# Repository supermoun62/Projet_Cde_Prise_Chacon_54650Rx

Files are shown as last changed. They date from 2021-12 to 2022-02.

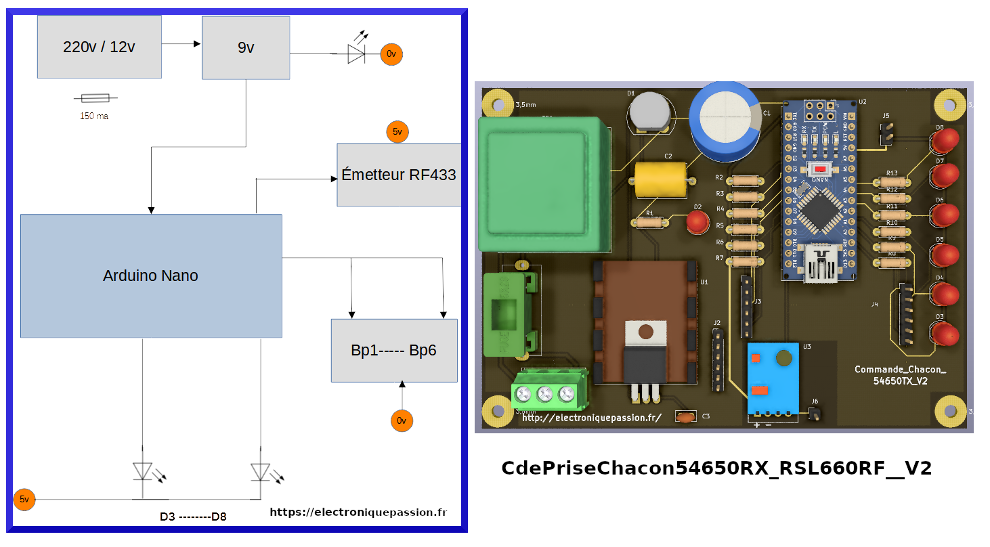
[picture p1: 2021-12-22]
Synopsis_CdePriseChacon54650RX_RSL660RF_Total.png

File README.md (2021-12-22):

# Projet_Cde_Prise_Chacon_54650Rx_ RSL3660R-F

Piloter 6 prises Chacon. L'ensemble comprend:

    Programmes Arduino:

    ReceiveDemo_Advanced
	ReceiveDemo_Simple
	CdePriseChacon54650RX_RSL660RF__V1
	CdePriseChacon54650RX_RSL660RF__V2

    Librairies rc_switch-2.6.3 et simpleBouton.

    Liste du matériel.

    Les schémas.
	Schema_Cde_Prise_Chacon_54650Rx_V1
	Schema_Cde_Prise_Chacon_54650Rx_V2
	Schema_Decodage_Chacon_54650TX

    Documentations Techniques.

    PCB en Gerber.

    PCB en PDF.

    Le fichier Arduino-Chacon_54650Rx_ RSL3660R-F.pdf
	contient le détail du projet.

   https://github.com/supermoun62/Projet_Cde_Prise_Chacon_54650Rx/blob/main/Synopsis_CdePriseChacon54650RX_RSL660RF_Total.png

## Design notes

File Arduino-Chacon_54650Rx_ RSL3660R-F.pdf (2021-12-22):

Arduino - Chacon_54650Rx_ RSL3660R-F

Arduino-Chacon_54650Rx_ RSL3660R-F | http://electroniquepassion.fr

### 1 Sur 19

## PROJET

Remplacer la télécommande Chacon Ref :54650RX_RSL3660R-F par un Arduino

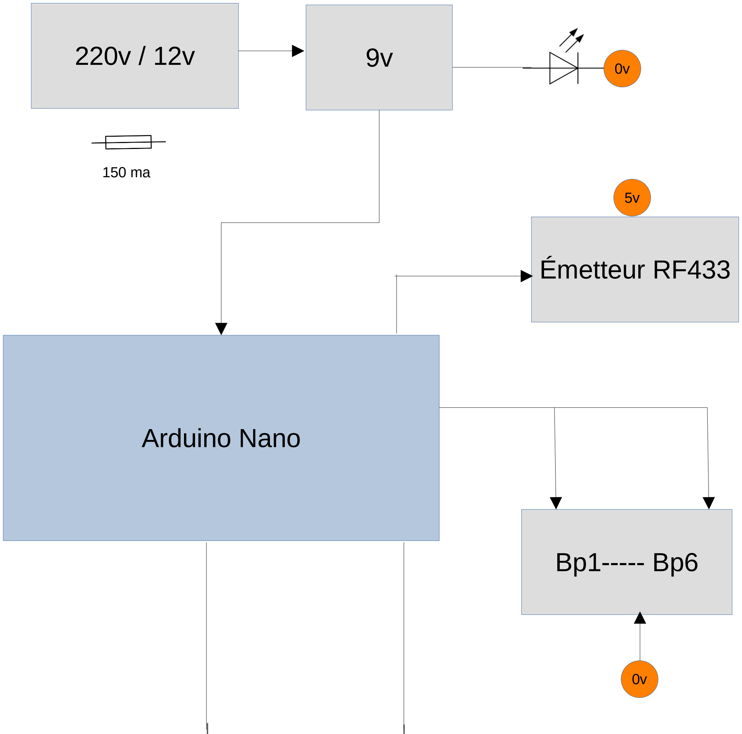
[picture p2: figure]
Arduino Nano; Émetteur RF433

### 2 Sur 19

Synopsis

5v
D3 --------D8

Matériel utilisé :

Télécommande Chacon : 54650TX_RSL366T

Prise Chacon : 54650RX-RSL3660R-F

Source : (https://github.com/sui77/rc-switch) | ReceiveDemo_Simple (https://github.com/sui77/rc-switch/tree/master/examples/ReceiveDemo_Simple) ReceiveDemo_Advanced (https://github.com/sui77/rc-switch/tree/master/examples/ReceiveDemo_Advanced)
Librairies : (https://github.com/sui77/rc-switch) | rc-switch (https://github.com/sui77/rc-switch)
| simpleBouton 1.4.2 (https://forum.arduino.cc/t/partage-boutons-poussoirs/361656)

### 3 Sur 19

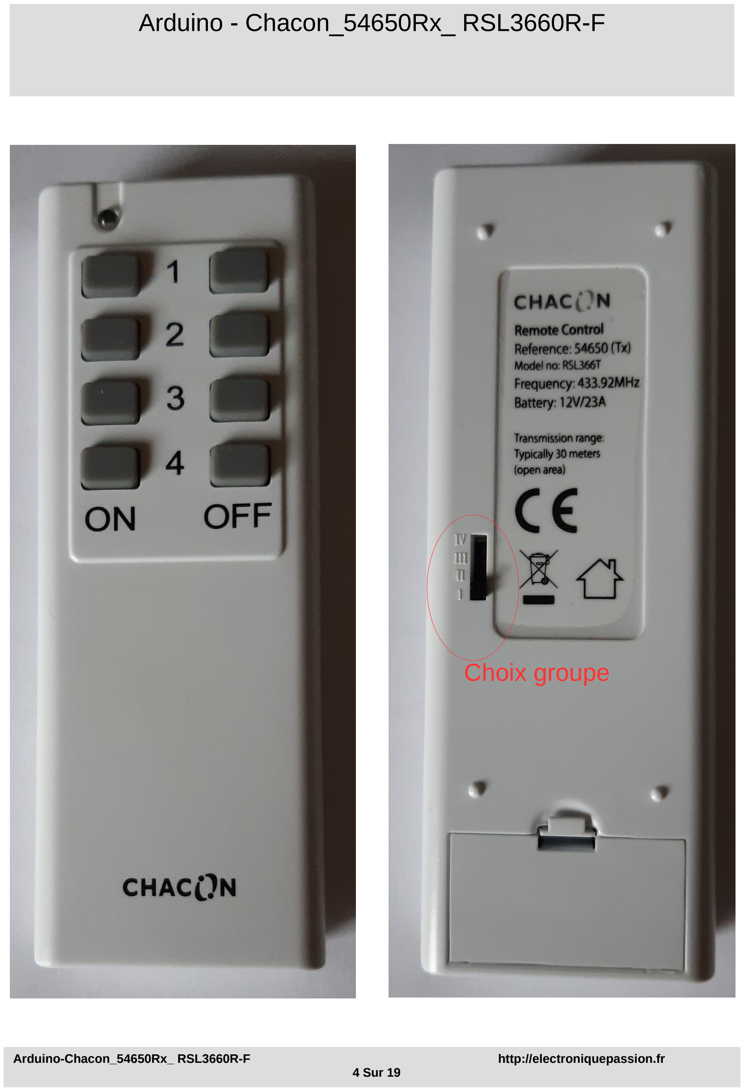
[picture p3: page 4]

Choix groupe

### 4 Sur 19

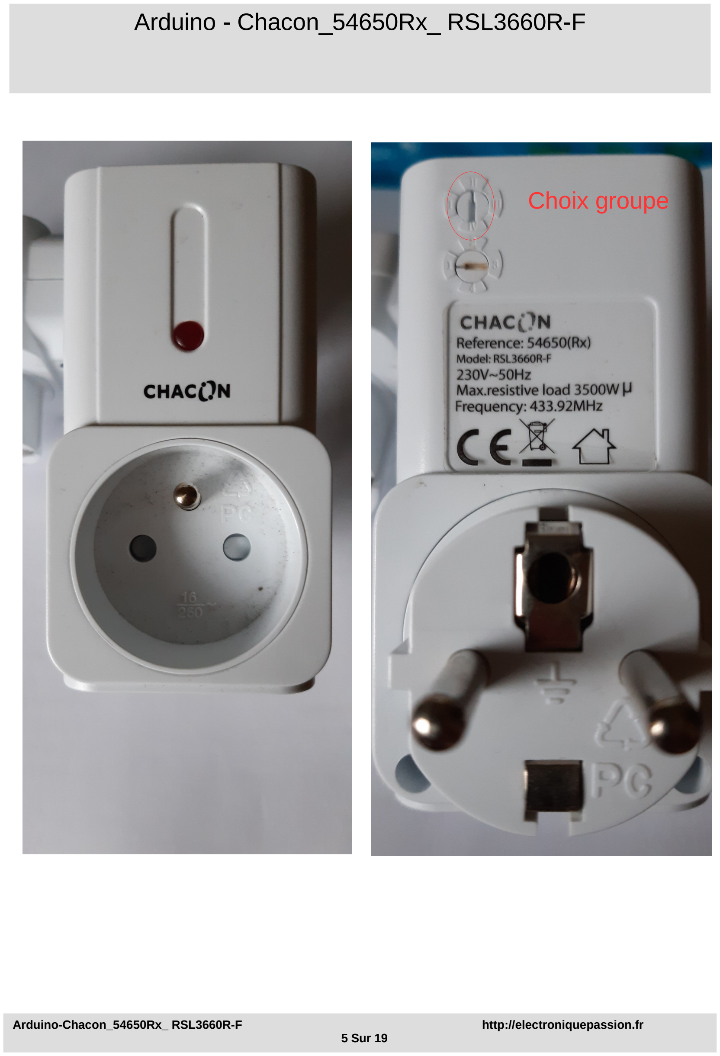
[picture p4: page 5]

Choix groupe

### 5 Sur 19

### 6 Sur 19

## Partie 1 Récupération signaux Télécommande

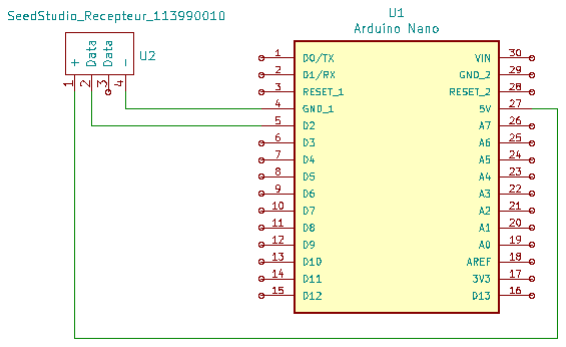
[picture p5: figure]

Programmes utilisés :

ReceiveDemo_Simple

ReceiveDemo_Advanced

DIGITAL PINS USABLE FOR INTERRUPTS : D2, D3

Schéma décodage Télécommande

### 7 Sur 19

ReceiveDemo_Simple BP1, BP2, BP3, BP4 groupe 1

BP1 OFF

BP1 ON

BP2 ON
BP2 OFF

BP3 ON
BP3 OFF

BP4 ON
BP4 OFF

Received 1381717 / 24bit Protocol: 1

Received 1381716 / 24bit Protocol: 1

Received 1394005 / 24bit Protocol: 1

Received 1394004 / 24bit Protocol: 1

Received 1397077 / 24bit Protocol: 1

Received 1397076 / 24bit Protocol: 1

Received 1397845 / 24bit Protocol: 1

Received 1397844 / 24bit Protocol: 1

### 8 Sur 19

ReceiveDemo_Advanced BP1, BP2, BP3, BP4 groupe 1

BP1 OFF

BP1 ON

BP2 ON

BP2 OFF

BP3 ON

BP3 OFF

BP4 ON

BP4 OFF

Decimal: 1381717 (24Bit) Binary: 000101010001010101010101 Tri-State: 0FFF 0FFF FFFF PulseLength: 414 microseconds Protocol: 1

Decimal: 1381716 (24Bit) Binary: 000101010001010101010100 Tri-State: 0FFF 0FFF FFF0 PulseLength: 412 microseconds Protocol: 1

Decimal: 1394005 (24Bit) Binary: 000101010100010101010101 Tri-State: 0FFF F0FF FFFF PulseLength: 412 microseconds Protocol: 1

Decimal: 1394004 (24Bit) Binary: 000101010100010101010100 Tri-State: 0FFF F0FF FFF0 PulseLength: 412 microseconds Protocol: 1

Decimal: 1397077 (24Bit) Binary: 000101010101000101010101 Tri-State: 0FFF FF0F FFFF PulseLength: 412 microseconds Protocol: 1

Decimal: 1397076 (24Bit) Binary: 000101010101000101010100 Tri-State: 0FFF FF0F FFF0 PulseLength: 412 microseconds Protocol: 1

Decimal: 1397845 (24Bit) Binary: 000101010101010001010101 Tri-State: 0FFF FFF0 FFFF PulseLength: 412 microseconds Protocol: 1

Decimal: 1397844 (24Bit) Binary: 000101010101010001010100 Tri-State: 0FFF FFF0 FFF0 PulseLength: 412 microseconds Protocol: 1

### 9 Sur 19

ReceiveDemo_Simple BP1, BP2, BP3, BP4 Groupe 2

BP1 OFF

BP1 ON

BP2 ON
BP2 OFF

BP3 ON
BP3 OFF

BP4 ON
BP4 OFF

Received 4527445 / 24bit Protocol: 1

Received 4527444 / 24bit Protocol: 1

Received 4539733 / 24bit Protocol: 1

Received 4539732 / 24bit Protocol: 1

Received 4542805 / 24bit Protocol: 1

Received 4542804 / 24bit Protocol: 1

Received 4543573 / 24bit Protocol: 1

Received 4543572 / 24bit Protocol: 1

### 10 Sur 19

ReceiveDemo_Advanced BP1, BP2, BP3, BP4 Groupe 2

BP1 OFF

BP1 ON

BP2 ON

BP2 OFF

BP3 ON

BP3 OFF

BP4 ON

BP4 OFF

Decimal: 4527445 (24Bit) Binary: 010001010001010101010101 Tri-State: F0FF 0FFF FFFF PulseLength: 412 microseconds Protocol: 1

Decimal: 4527444 (24Bit) Binary: 010001010001010101010100 Tri-State: F0FF 0FFF FFF0 PulseLength: 412 microseconds Protocol: 1

Decimal: 4539733 (24Bit) Binary: 010001010100010101010101 Tri-State: F0FF F0FF FFFF PulseLength: 412 microseconds Protocol:

Decimal: 4539732 (24Bit) Binary: 010001010100010101010100 Tri-State: F0FF F0FF FFF0 PulseLength: 412 microseconds Protocol: 1

Decimal: 4542805 (24Bit) Binary: 010001010101000101010101 Tri-State: F0FF FF0F FFFF PulseLength: 412 microseconds Protocol: 1

Decimal: 4542804 (24Bit) Binary: 010001010101000101010100 Tri-State: F0FF FF0F FFF0 PulseLength: 412 microseconds Protocol: 1

Decimal: 4543573 (24Bit) Binary: 010001010101010001010101 Tri-State: F0FF FFF0 FFFF PulseLength: 412 microseconds Protocol: 1

Decimal: 4543572 (24Bit) Binary: 010001010101010001010100 Tri-State: F0FF FFF0 FFF0 PulseLength: 411 microseconds Protocol: 1

### 11 Sur 19

### 12 Sur 19

## Partie 2 Commande avec Arduino

V1

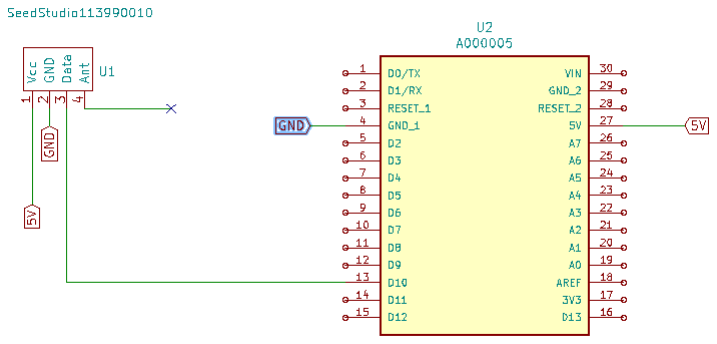
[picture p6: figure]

### 13 Sur 19

Schéma commande prises V1

Dans le dossier :

Projet_Cde_Prise_Chacon_54650Rx

Schema_Cde_Prise_Chacon_54650Rx_V1.pdf

Programme:

CdePriseChacon54650RX_RSL660RF__V1

### 14 Sur 19

Schéma commande prises V2

Dans le dossier :

Schema_Cde_Prise_Chacon_54650Rx_V2

Schema_Commande_Chacon_54650TX_V2.pdf

Programme:

CdePriseChacon54650RX_RSL660RF__V2

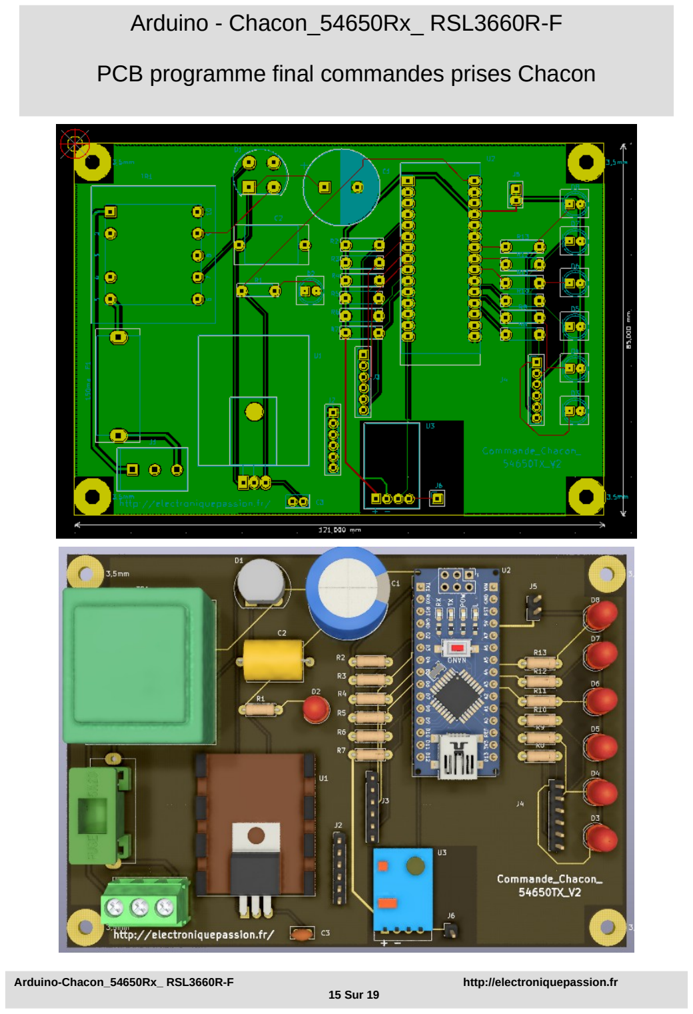
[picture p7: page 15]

### 15 Sur 19

PCB programme final commandes prises Chacon

PCB programme final commandes prises Chacon

### 16 Sur 19

Dossiers:

Projet_Cde_Prise_Chacon_54650Rx

Schema_Cde_Prise_Chacon_54650Rx_V2

PCB_Gerber_Commande_Chacon_54650TX_V2

PCB_PDF_Commande_Chacon_54650TX_V2

Liste_Materiel_Commande_Chacon_54650TX

Chez JlCPCB nécessite l’envoi du dossier:

PCB_Gerber_Commande_Chacon_54650TX_V2.rar

Poser Arduino Nano sur deux supports 15br avant soudure

Ne pas oublier de pose de la pâte thermique au niveau du régulateur.

PCB embase 15br

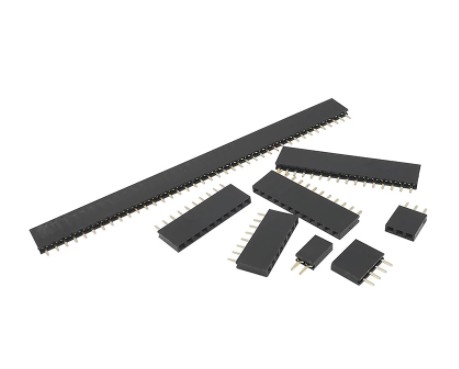
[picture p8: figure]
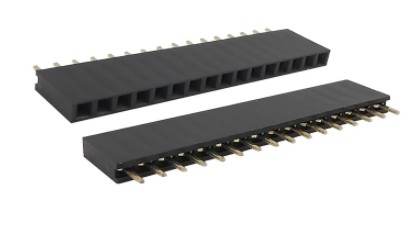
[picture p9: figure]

### 17 Sur 19

https://fr.aliexpress.com/item/4000852908837.html?spm=a2g0s.9042311.0.0.41a46c372WkNYm

### 18 Sur 19

Complément

# COMPLEMENT

# Tests effectués avec des prises SmartHome

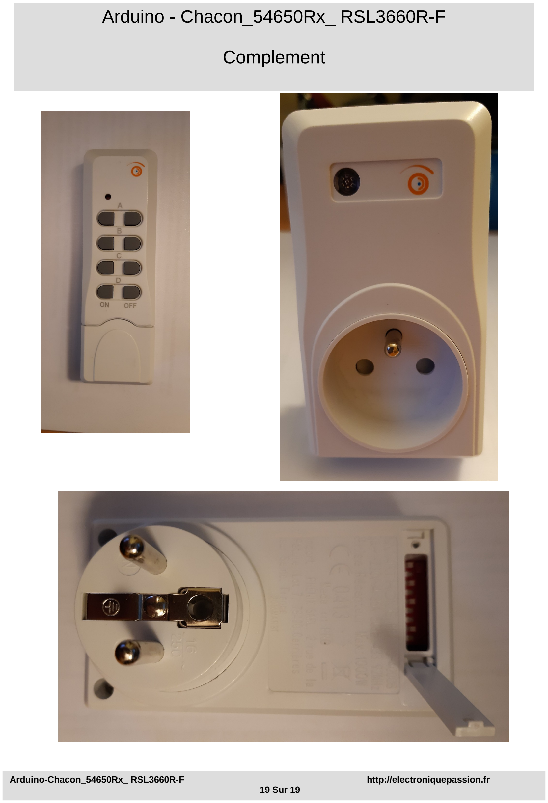
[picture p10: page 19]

Complement

### 19 Sur 19

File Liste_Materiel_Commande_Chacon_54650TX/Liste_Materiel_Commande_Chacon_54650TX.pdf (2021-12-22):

1 sur 2 | CdePriseChacon54650RX_RSL660RF
Title | Cde_Prise_Chacon_54650Rx_ RSL3660R-F
Company | Christian Mercier 62128 Boiry-Becquerelle
Revision | V2
Date Issue | 07/11/21
| | TME Electronic | SeedStudio | Lextronic | Farnell
C1 | 2200uf | KM2200/25 (https://www.tme.eu/fr/details/km2200_25/condensateurs-electrolytiques-tht-105degc/samxon/km-2200u-25v/)
C2 | 330nf | BFC233820334 (https://www.tme.eu/fr/details/bfc233820334/condensateurs-polypropylene-x2-y2/vishay/)
C3 | 100nf | CCK-100N (https://www.tme.eu/fr/details/cck-100n/condensateurs-ceramiques-tht-100v/sr-passives/)
D1 | Redresseur | B40C1500G-E4 (https://www.tme.eu/fr/details/b40c1500g-e4_51/redresseurs-monophases-a-diodes-ronds/vishay/)
D2 | Verte 2v | OSNG5134A (https://www.tme.eu/fr/details/osng5134a/diodes-led-tht-5mm/optosupply/)
D3 | Rouge 2v | SLR-56VR3F
D4 | Rouge 2v | SLR-56VR3F
D5 | Rouge 2v | SLR-56VR3F
D6 | Rouge 2v | SLR-56VR3F
D7 | Rouge 2v | SLR-56VR3F
D8 | Rouge 2v | SLR-56VR3F (https://www.tme.eu/fr/katalog/?art=SLR-56VR3F)
F1 | Support Fusibles 696108003002 | ZHL77 (https://www.tme.eu/fr/details/zhl77/porte-fusibles-pcb/stelvio-kontek/ptf-77/)
| Capot 696122003001 | ZHL7X-H (https://www.tme.eu/fr/details/zhl7x-h/porte-fusibles-pcb/stelvio-kontek/bs232/)
J1 | Connecteur 1888690 | MKDSN2.5/3-5.08 (https://www.tme.eu/fr/katalog/?search=MKDSN+2%2C5%2F+3-5%2C08&s_field=1000011&s_order=desc)
J2 | PinHeader_1x06_P2.54mm_Vertical
J3 | PinHeader_1x06_P2.54mm_Vertical
J4 | PinHeader_1x06_P2.54mm_Vertical
J5 | PinHeader_1x02_P2.54mm_Vertical
J6 | PinHeader_1x01_P2.54mm_Vertical
R1 | 1,5k - 1 %
R10 | 1,5k – 1 %
R11 | 1,5k – 1 %
R12 | 1,5k – 1 %
R13 | 1,5k – 1 %
R2 | 10k – 1 %
R3 | 10k – 1 %
R4 | 10k – 1 %
R5 | 10k – 1 %

2 sur 2 | CdePriseChacon54650RX_RSL660RF
R6 | 10k – 1 %
R7 | 10k – 1 %
R8 | 1,5k – 1 %
R9 | 1,5k – 1 %
TR1 | 220v / 12v -1,5VA | | | | 1689049 (https://fr.farnell.com/myrra/44087/transformateur-1-5va-12v/dp/1689049?ost=168-9049)
U1 | Régulateur 9v | NTE1910 (https://www.tme.eu/fr/katalog/?search=NTE1910&s_field=1000011&s_order=desc)
U2 | Arduino Nano
U3 | SeedStudio113990010 | | 113990010
*2 | Support 15br
| Connecteur mâle double Rangée Sécable | | | CC066
| Connecteur mâle simple Rangée Secable | | | CC076
| Connecteur 10 broches mâles pas 2,54 | 1-826629-0 (https://www.tme.eu/fr/details/1-826629-0/barres-et-socles-a-broches/te-connectivity/)
| Refroidisseur | FK210SACB (https://www.tme.eu/fr/katalog/?search=FK210SACB&s_field=1000011&s_order=desc)
| Pâte thermique KP12 4.2 g

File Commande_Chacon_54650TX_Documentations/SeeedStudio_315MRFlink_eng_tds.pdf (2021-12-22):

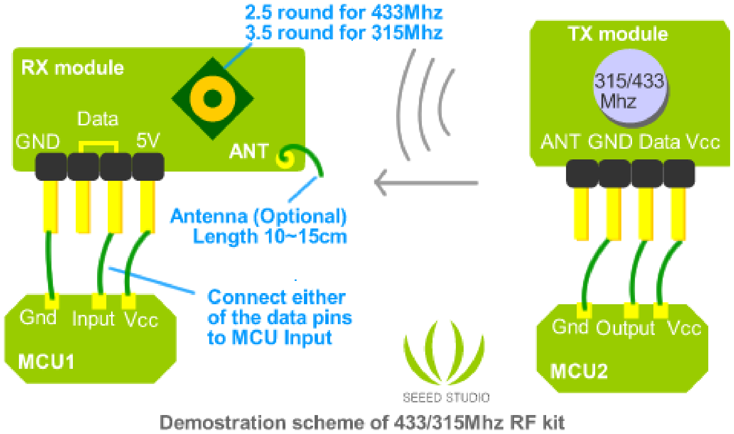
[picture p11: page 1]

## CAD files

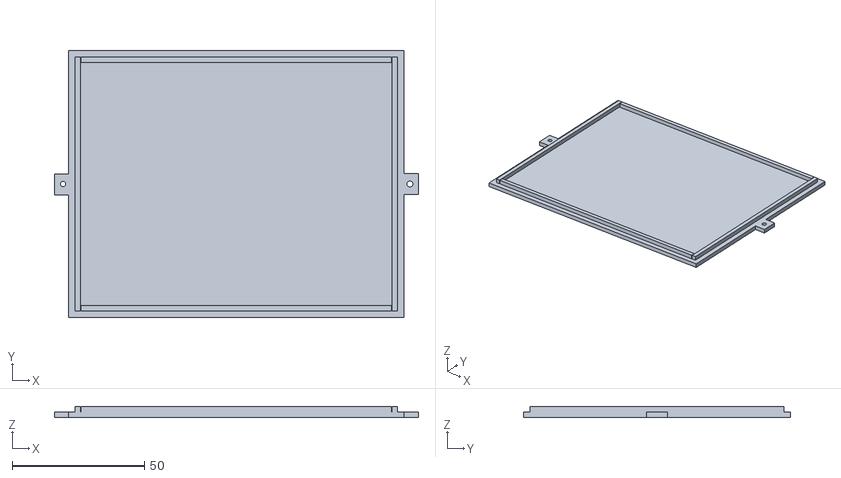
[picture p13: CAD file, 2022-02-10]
Coffret et Couvercle STL/Couvercle Cde Prises Chacon 54650RX.stl
137.8 x 101.0 x 4.00

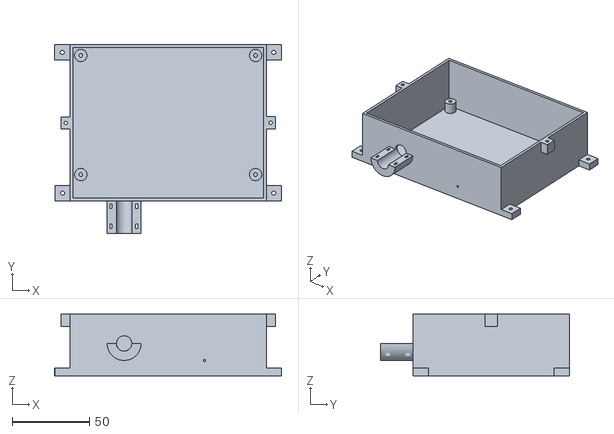
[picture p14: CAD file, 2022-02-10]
Coffret et Couvercle STL/Coffret Cde Prises Chacon 54650RX.stl
146.8 x 122.0 x 40.0

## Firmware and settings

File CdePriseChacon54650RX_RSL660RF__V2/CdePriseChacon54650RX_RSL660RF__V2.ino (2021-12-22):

/* Synopsis: Cde Prise Chacon 54650RX_RSL660RF__V2
   Carte   : Arduino Nano
   Capteur : Emetteur 433.   
             
  Biblio:  ReceiveDemo_Simple 
           simpleBouton.h 1.4.2   
             
   Source  : https://github.com/sui77/rc-switch/blob/master/examples/ReceiveDemo_Simple/ReceiveDemo_Simple.ino
             https://forum.arduino.cc/index.php?topic=375232.0 
             http://forum.arduino.cc/index.php?topic=398112.0
           
   https://electroniquepassion.fr/ 
   C.Mercier  62128 Boiry-Becquerelle  
*/
//-----------------------------------------------------------------
#include <simpleBouton.h>
//Cablage : pin---BP---GND
const uint8_t pin_bouton1 = 2;//pin 5 du Nano
const uint8_t pin_bouton2 = 3;//pin 6 du Nano
const uint8_t pin_bouton3 = 4;//pin 7 du Nano
const uint8_t pin_bouton4 = 5;//pin 8 du Nano
const uint8_t pin_bouton5 = 6;//pin 9 du Nano
const uint8_t pin_bouton6 = 7;//pin 10 du Nano
simpleBouton bouton1(pin_bouton1);
simpleBouton bouton2(pin_bouton2);
simpleBouton bouton3(pin_bouton3);
simpleBouton bouton4(pin_bouton4);
simpleBouton bouton5(pin_bouton5);
simpleBouton bouton6(pin_bouton6);
//-------------------------------------
#include <RCSwitch.h>
RCSwitch mySwitch = RCSwitch();
//-------------------------------------
bool prise1 = false;
bool bit1 = false;
bool prise2 = false;
bool bit2 = false;
bool prise3 = false;
bool bit3 = false;
bool prise4 = false;
bool bit4 = false;
bool prise5 = false;
bool bit5 = false;
bool prise6 = false;
bool bit6 = false; 
const int ledPrise1 = A0;
const int ledPrise2 = A1;
const int ledPrise3 = A2;
const int ledPrise4 = A3;
const int ledPrise5 = A4;
const int ledPrise6 = A5;
const int led13 = 13;
//Ne pas utiliser les sorties A6 et A7 en digital.
//-------------------------------------
void setup()
{  
  //Serial.begin(9600);  
  mySwitch.enableTransmit(12);// Transmission par la sortie 12 pin 15 du Nano  
  pinMode(ledPrise1, OUTPUT);
  pinMode(ledPrise2, OUTPUT);
  pinMode(ledPrise3, OUTPUT);
  pinMode(ledPrise4, OUTPUT);
  pinMode(ledPrise5, OUTPUT);
  pinMode(ledPrise6, OUTPUT);
  pinMode(led13, INPUT_PULLUP);    
  digitalWrite(ledPrise1, LOW);
  digitalWrite(ledPrise2, LOW);
  digitalWrite(ledPrise3, LOW);
  digitalWrite(ledPrise4, LOW);
  digitalWrite(ledPrise5, LOW);
  digitalWrite(ledPrise6, LOW); 
  //A la mise sous tension, mise en OFF de toutes les prises
  mySwitch.send(1381716, 24);
  delay(150);
  mySwitch.send(1394004, 24);
  delay(150);
  mySwitch.send(1397076, 24);
  delay(150);
  mySwitch.send(1397844, 24);
  delay(150);
  mySwitch.send(4539732, 24);
  delay(150);
  mySwitch.send(4542804, 24); 
  digitalWrite(ledPrise1, HIGH);
  digitalWrite(ledPrise2, HIGH);
  digitalWrite(ledPrise3, HIGH);
  digitalWrite(ledPrise4, HIGH);
  digitalWrite(ledPrise5, HIGH);
  digitalWrite(ledPrise6, HIGH);  
  delay(1000);
}//FIN SETUP---------------------------
void loop()
{  
bouton1.actualiser();  
if (bouton1.vientDEtreEnfonce())
  {
    prise1 = !prise1; //inversion
  } 

if (prise1 == true && bit1 == false)
  {
    // on envoie la trame "on"
    //mySwitch.send("010001010101000101010101");
    mySwitch.send(4542805, 24);
    bit1 = true;
    digitalWrite(ledPrise1, LOW);   
  }

if (prise1 == false && bit1 == true)
  {
    // on envoie la trame "off"
    mySwitch.send(4542804, 24);
    bit1 = false;
    digitalWrite(ledPrise1, HIGH);
  }
//-------------------------------------
bouton2.actualiser();  
if (bouton2.vientDEtreEnfonce())
  {
    prise2 = !prise2; //inversion
  } 

if (prise2 == true && bit2 == false)
  {
    // on envoie la trame "on"
    //mySwitch.send("000101010001010101010101");
    //mySwitch.send(1381717, 24);
    bit2 = true;
    digitalWrite(ledPrise2, LOW);
  }

if (prise2 == false && bit2 == true)
  {
    // on envoie la trame "off" 
    //mySwitch.send("000101010001010101010100");
    //mySwitch.send(1381716, 24);
    bit2 = false; 
    digitalWrite(ledPrise2, HIGH);
  }
//-------------------------------------
bouton3.actualiser();  
if (bouton3.vientDEtreEnfonce())
  {
    prise3 = !prise3; //inversion
  } 

if (prise3 == true && bit3 == false)
  {
    // on envoie la trame "on"
    //mySwitch.send("000101010001010101010101");
    //mySwitch.send(1381717, 24);
    bit3 = true;
    digitalWrite(ledPrise3, LOW);
  }

if (prise3 == false && bit3 == true)
  {
    // on envoie la trame "off" 
    //mySwitch.send("000101010001010101010100");
    //mySwitch.send(1381716, 24);
    bit3 = false; 
    digitalWrite(ledPrise3, HIGH);
  }
//-------------------------------------
bouton4.actualiser();  
if (bouton4.vientDEtreEnfonce())
  {
    prise4 = !prise4; //inversion
  } 

if (prise4 == true && bit4 == false)
  {
    // on envoie la trame "on"
    //mySwitch.send("000101010001010101010101");
    //mySwitch.send(1381717, 24);
    bit4 = true;
    digitalWrite(ledPrise4, LOW);
  }

if (prise4 == false && bit4 == true)
  {
    // on envoie la trame "off" 
    //mySwitch.send("000101010001010101010100");
    //mySwitch.send(1381716, 24);
    bit4 = false; 
    digitalWrite(ledPrise4, HIGH);
  }
//-------------------------------------
bouton5.actualiser();  
if (bouton5.vientDEtreEnfonce())
  {
    prise5 = !prise5; //inversion
  } 

if (prise5 == true && bit5 == false)
  {
    // on envoie la trame "on"
    //mySwitch.send("000101010001010101010101");
    //mySwitch.send(1381717, 24);
    bit5 = true;
    digitalWrite(ledPrise5, LOW);
  }

if (prise5 == false && bit5 == true)
  {
    // on envoie la trame "off" 
    //mySwitch.send("000101010001010101010100");
    //mySwitch.send(1381716, 24);
    bit5 = false; 
    digitalWrite(ledPrise5, HIGH);
  }
//-------------------------------------
bouton6.actualiser();  
if (bouton6.vientDEtreEnfonce())
  {
    prise6 = !prise6; //inversion
  } 

if (prise6 == true && bit6 == false)
  {
    // on envoie la trame "on"
    //mySwitch.send("000101010001010101010101");
    mySwitch.send(1381717, 24);
    bit6 = true;
    digitalWrite(ledPrise6, LOW);
  }

if (prise6 == false && bit6 == true)
  {
    // on envoie la trame "off" 
    //mySwitch.send("000101010001010101010100");
    mySwitch.send(1381716, 24);
    bit6 = false; 
    digitalWrite(ledPrise6, HIGH);
  }  
}//Fin LOOP  

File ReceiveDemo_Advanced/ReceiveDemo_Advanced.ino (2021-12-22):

/*
  Example for receiving
  
  https://github.com/sui77/rc-switch/
  
  If you want to visualize a telegram copy the raw data and 
  paste it into http://test.sui.li/oszi/
*/

#include <RCSwitch.h>

RCSwitch mySwitch = RCSwitch();

void setup() {
  Serial.begin(9600);
  mySwitch.enableReceive(0);  // Receiver on interrupt 0 => that is pin #2
  //mySwitch.enableReceive(1);  // Receiver on interrupt 0 => that is pin #3
}

void loop() {
  if (mySwitch.available()) {
    output(mySwitch.getReceivedValue(), mySwitch.getReceivedBitlength(), mySwitch.getReceivedDelay(), mySwitch.getReceivedRawdata(),mySwitch.getReceivedProtocol());
    mySwitch.resetAvailable();
  }
}

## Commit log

2021-12-22 C. Mercier 1er Commit 22/12/2021
    [Schema_Commande_Chacon_54650TX_V2-B_Adhes.gbr, Schema_Commande_Chacon_54650TX_V2-B_CrtYd.gbr, Schema_Commande_Chacon_54650TX_V2-B_Cu.gbr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]
2022-02-10 C. Mercier Ajout dossier STL 10/02/2022
    [Coffret Cde Prises Chacon 54650RX.stl, Couvercle Cde Prises Chacon 54650RX.stl]
